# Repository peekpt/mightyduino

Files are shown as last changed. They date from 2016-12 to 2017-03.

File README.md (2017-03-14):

## Mightyduino
A DIY Arduino type hardware board based on ATmega644p Atmega1284p

This project is free and based on @MCUDude's [MightyCore](https://github.com/MCUdude/MightyCore) which has awesome well designed kits for serious development with AVR's.
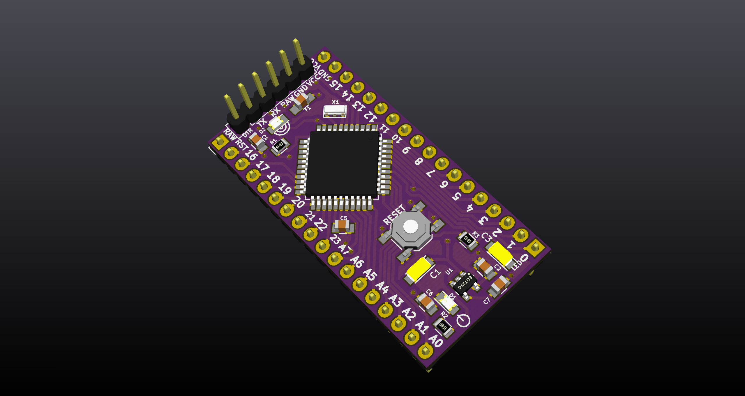
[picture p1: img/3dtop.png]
top


Mightyduino is an Arduino with more memory than an Arduino Pro mini. It can use 644p (64k) or 1284p (128k) chips. Its voltage can be configured by U1 and the frequecy can be configured by the Murata's ressonator (crystal).
It has a power led and another one connected to pin D0. The push button performs reset. DTR pin can be used to external reset. The RAW pin is the input voltage **<16v**. The VCC pin is the regulator output and IC voltage, it can be loaded up to peak of **500mA**.

To burn the **bootloader** (optiboot 6.0) you must first install the [MightyCore boards](https://github.com/MCUdude/MightyCore#how-to-install) on Arduino App  , connect the ICSP pins to your bootloader programming hardware (eg. USBASP), select one of MCUDude's board that meet the specs you use and burn bootloader.
Then you can access (ttl-serial dongle) like a normal arduino on the serial pins (like arduino pro mini). Mightyduino uses the 'standard' pin mapping.

###Version History
- v1.3 - Changed C1 C3 footprint, add reset pin for SPI programming.
- v1.2 - Switch U1 shutdown pin 3 voltage to RAW
- v1.1 - Switched Led from pin D13 to D0, cosmetic improvements
- v1.0 - Initial release

###Quick Links:

Order boards from [OSHPark]
(https://oshpark.com/shared_projects/zuZ4OIae)

Or download the [Gerber files](https://github.com/peekpt/mightyduino/raw/master/gerber/gerbers.zip) for other pcb maker

Download the schematic [PDF](https://github.com/peekpt/mightyduino/blob/master/schematic.pdf)

ATmega datasheet [644p](http://www.atmel.com/images/doc2593.pdf) [1284p](http://www.atmel.com/images/doc8059.pdf)

## Screenshots

###Components
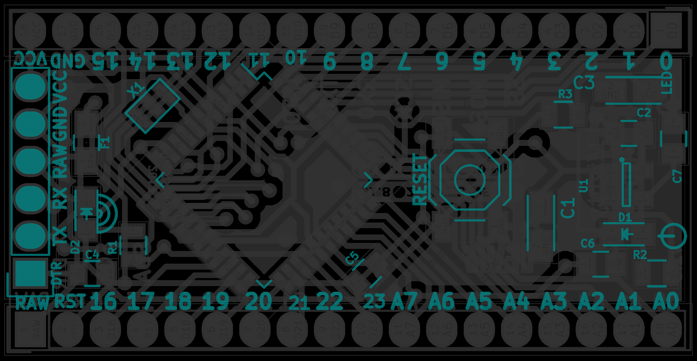
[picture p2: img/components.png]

### Top
top
### Bottom
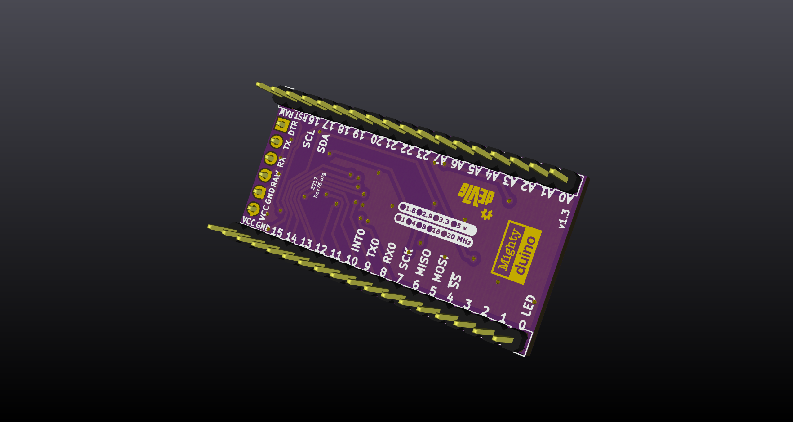
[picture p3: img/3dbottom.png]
bottom

###Pin Mapping
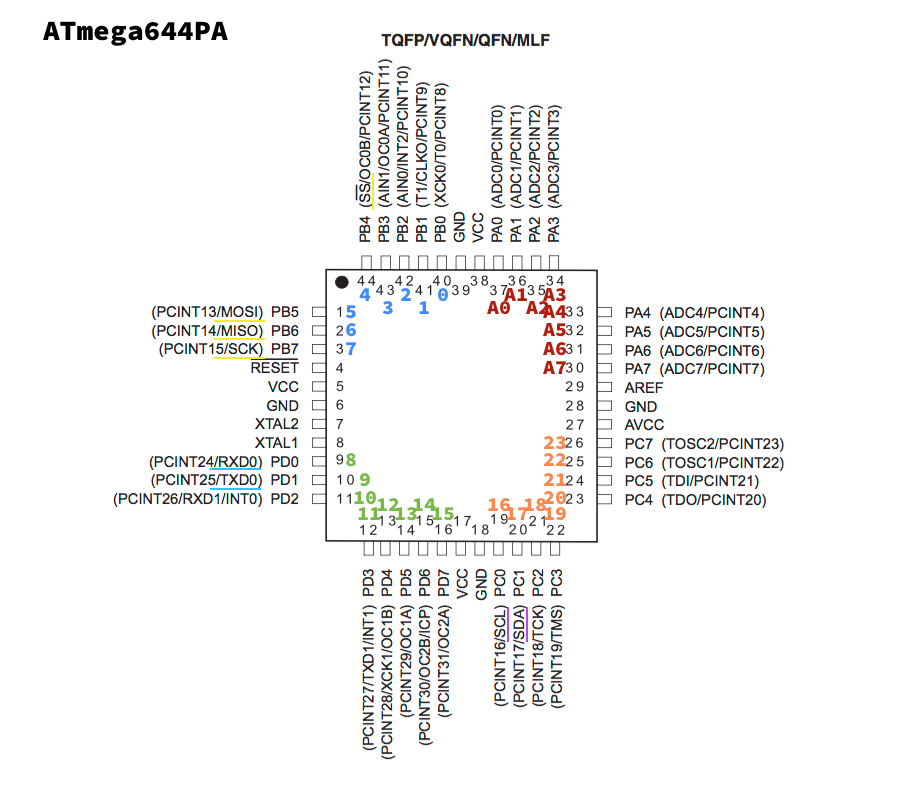
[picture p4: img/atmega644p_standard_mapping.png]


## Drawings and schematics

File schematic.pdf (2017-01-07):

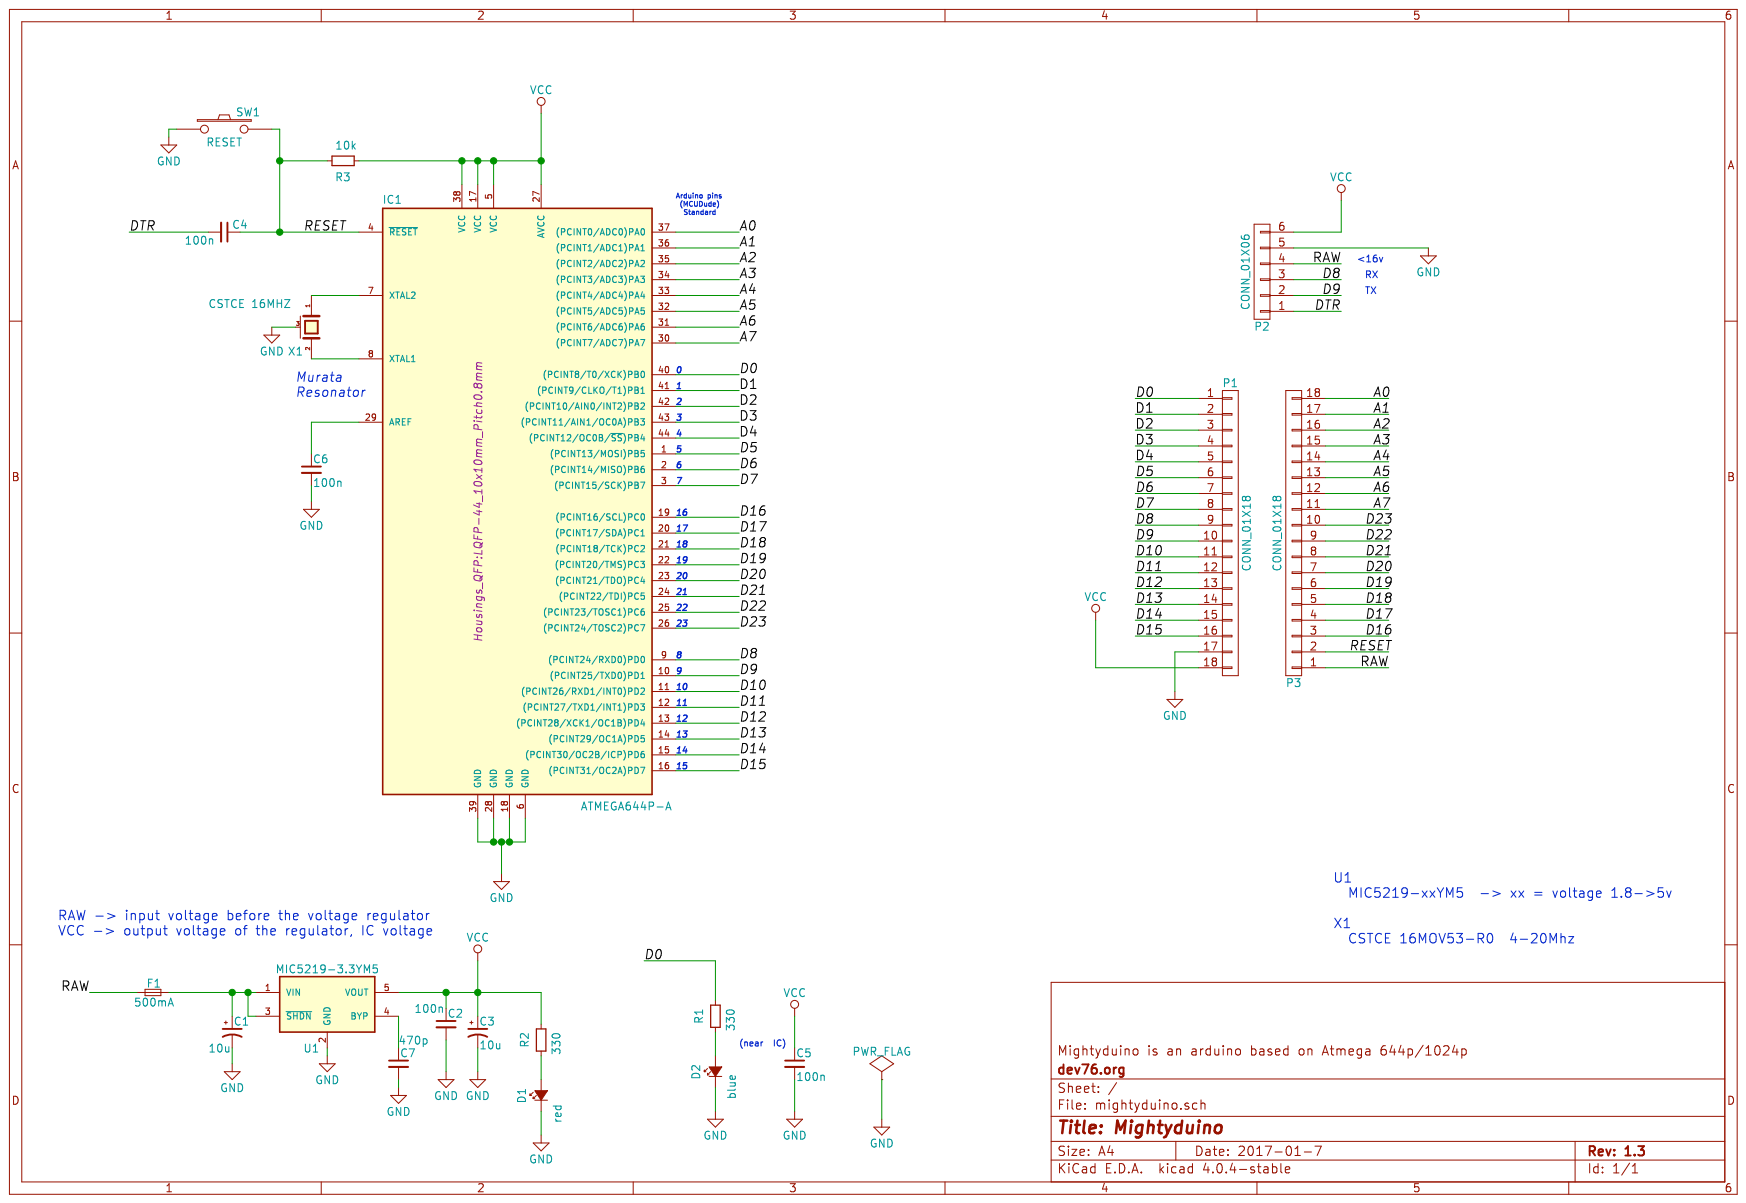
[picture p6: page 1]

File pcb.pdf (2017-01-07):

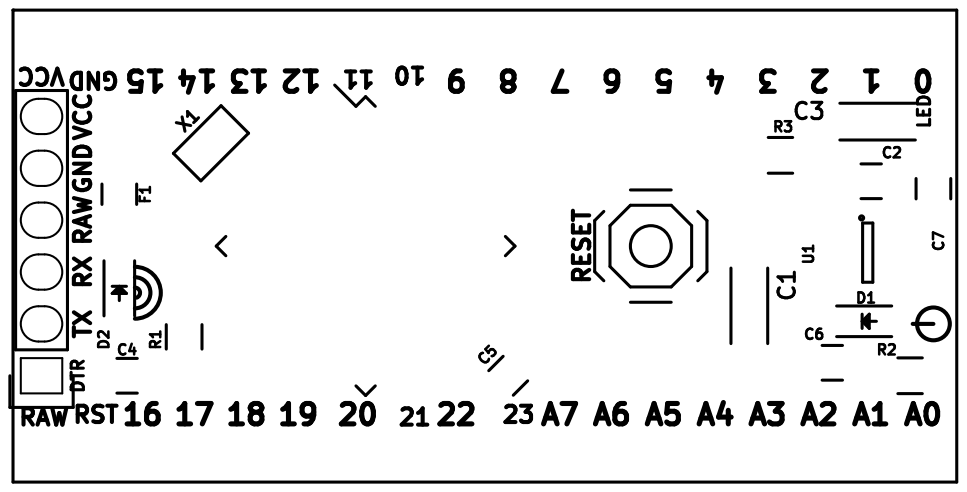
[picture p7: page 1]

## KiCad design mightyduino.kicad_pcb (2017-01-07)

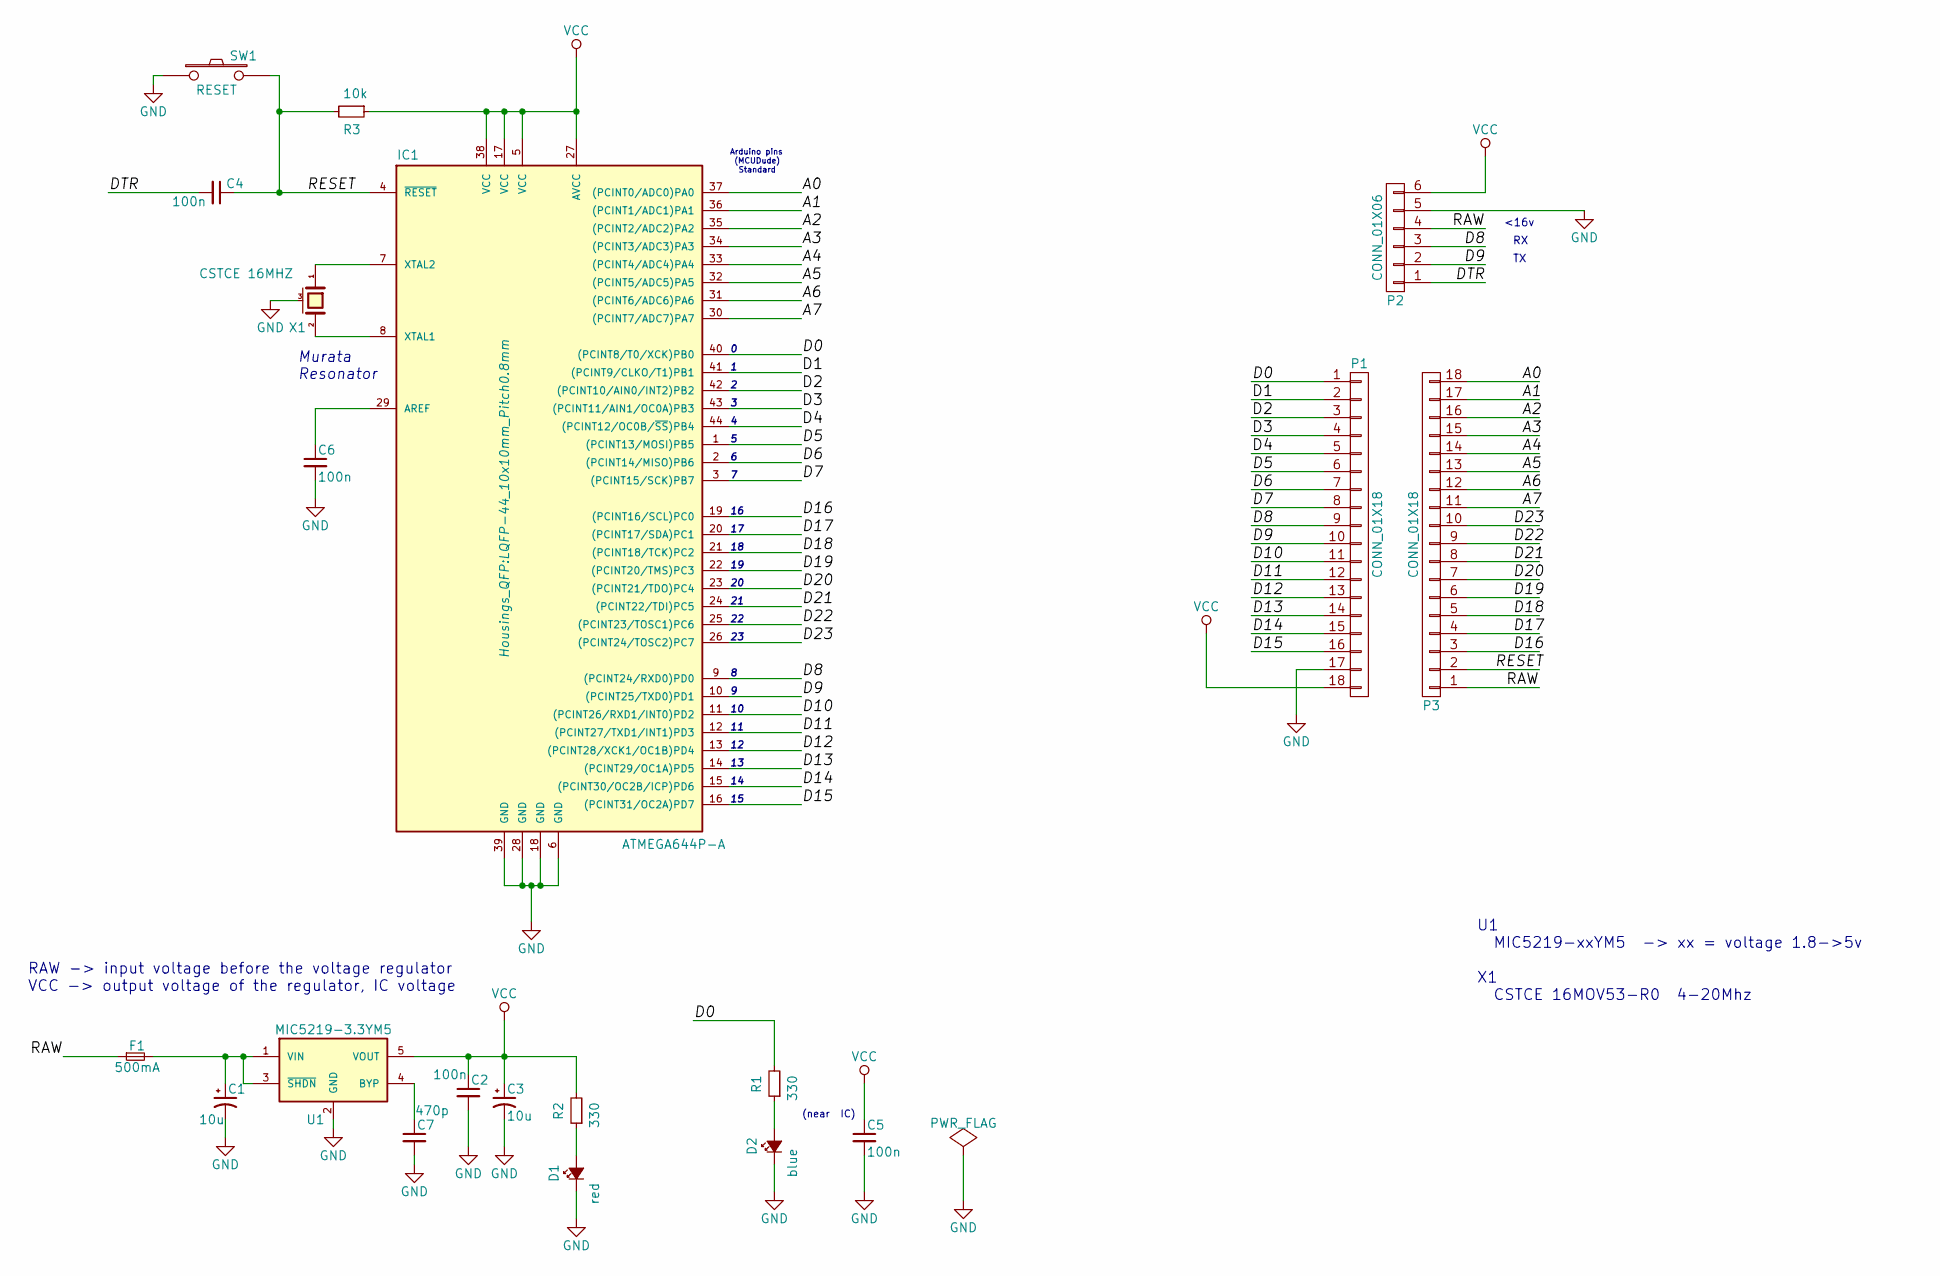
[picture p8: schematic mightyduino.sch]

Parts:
C1, C3: 10u; TantalC_SizeA_EIA-3216_Reflow
C2, C4, C5, C6: 100n; C_0805
C7: 470p; C_0805
D1: red; LED_0805
D2: blue; LED_0805
F1: 500mA; C_0805_HandSoldering
IC1: ATMEGA644P-A; LQFP-44_10x10mm_Pitch0.8mm
P1, P3: CONN_01X18; Pin_Header_Straight_1x18
P2: CONN_01X06; Pin_Header_Straight_1x06
R1, R2: 330; R_0805
R3: 10k; R_0805
SW1: RESET; SW_SPST_TL3342
U1: MIC5219-3.3YM5; SOT-23-5
X1: CSTCE 16MHZ; CSTCEv2

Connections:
/A0: IC1.37 ((PCINT0/ADC0)PA0), P3.18
/A1: IC1.36 ((PCINT1/ADC1)PA1), P3.17
/A2: IC1.35 ((PCINT2/ADC2)PA2), P3.16
/A3: IC1.34 ((PCINT3/ADC3)PA3), P3.15
/A4: IC1.33 ((PCINT4/ADC4)PA4), P3.14
/A5: IC1.32 ((PCINT5/ADC5)PA5), P3.13
/A6: IC1.31 ((PCINT6/ADC6)PA6), P3.12
/A7: IC1.30 ((PCINT7/ADC7)PA7), P3.11
/D0: IC1.40 ((PCINT8/T0/XCK)PB0), P1.1, R1.2
/D1: IC1.41 ((PCINT9/CLKO/T1)PB1), P1.2
/D2: IC1.42 ((PCINT10/AIN0/INT2)PB2), P1.3
/D3: IC1.43 ((PCINT11/AIN1/OC0A)PB3), P1.4
/D4: IC1.44 ((PCINT12/OC0B/~SS~)PB4), P1.5
/D5: IC1.1 ((PCINT13/MOSI)PB5), P1.6
/D6: IC1.2 ((PCINT14/MISO)PB6), P1.7
/D7: IC1.3 ((PCINT15/SCK)PB7), P1.8
/D8: IC1.9 ((PCINT24/RXD0)PD0), P1.9, P2.3
/D9: IC1.10 ((PCINT25/TXD0)PD1), P1.10, P2.2
/D10: IC1.11 ((PCINT26/RXD1/INT0)PD2), P1.11
/D11: IC1.12 ((PCINT27/TXD1/INT1)PD3), P1.12
/D12: IC1.13 ((PCINT28/XCK1/OC1B)PD4), P1.13
/D13: IC1.14 ((PCINT29/OC1A)PD5), P1.14
/D14: IC1.15 ((PCINT30/OC2B/ICP)PD6), P1.15
/D15: IC1.16 ((PCINT31/OC2A)PD7), P1.16
/D16: IC1.19 ((PCINT16/SCL)PC0), P3.3
/D17: IC1.20 ((PCINT17/SDA)PC1), P3.4
/D18: IC1.21 ((PCINT18/TCK)PC2), P3.5
/D19: IC1.22 ((PCINT20/TMS)PC3), P3.6
/D20: IC1.23 ((PCINT21/TDO)PC4), P3.7
/D21: IC1.24 ((PCINT22/TDI)PC5), P3.8
/D22: IC1.25 ((PCINT23/TOSC1)PC6), P3.9
/D23: IC1.26 ((PCINT24/TOSC2)PC7), P3.10
/DTR: C4.2, P2.1
/RAW: F1.1, P2.4, P3.1
/RESET: C4.1, IC1.4 (~RESET), P3.2, R3.2, SW1.2
GND: C1.2, C2.2, C3.2, C5.2, C6.2, C7.2, D1.1 (K), D2.1 (K), IC1.6 (GND), IC1.18 (GND), IC1.28 (GND), IC1.39 (GND), P1.17, P2.5, SW1.1, U1.2 (GND), X1.3 (case)
unnamed: C1.1, F1.2, U1.1 (VIN), U1.3 (~SHDN~)
unnamed: C6.1, IC1.29 (AREF)
unnamed: C7.1, U1.4 (BYP)
unnamed: D1.2 (A), R2.1
unnamed: D2.2 (A), R1.1
unnamed: IC1.7 (XTAL2), X1.1
unnamed: IC1.8 (XTAL1), X1.2
VCC: C2.1, C3.1, C5.1, IC1.5 (VCC), IC1.17 (VCC), IC1.27 (AVCC), IC1.38 (VCC), P1.18, P2.6, R2.2, R3.1, U1.5 (VOUT)

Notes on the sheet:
Murata Resonator
Arduino pins (MCUDude) Standard
(near IC)
<16v
U1 MIC5219-xxYM5 -> xx = voltage 1.8->5v X1 CSTCE 16MOV53-R0 4-20Mhz
RAW -> input voltage before the voltage regulator VCC -> output voltage of the regulator, IC voltage

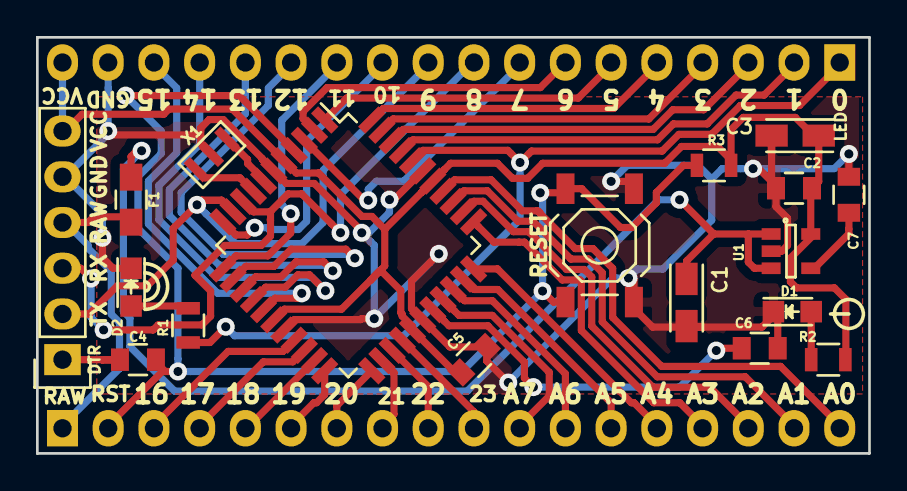
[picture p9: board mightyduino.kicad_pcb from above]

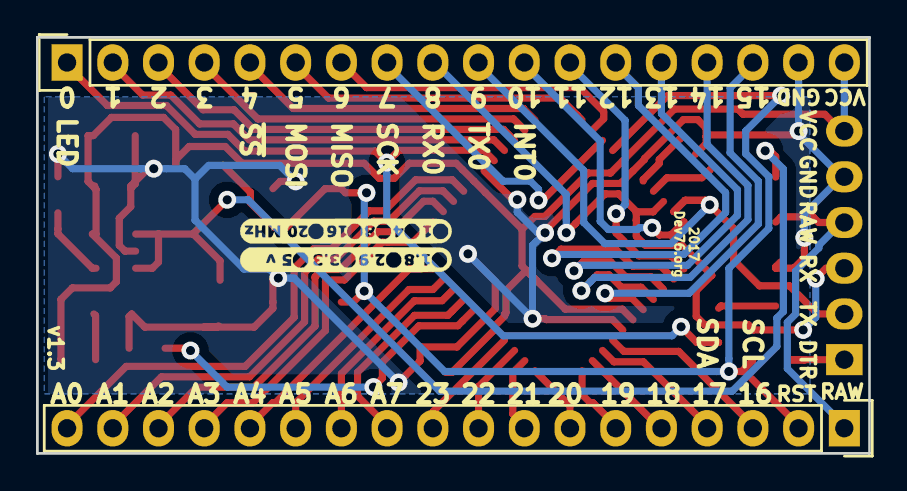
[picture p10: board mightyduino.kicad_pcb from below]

Board: 2 copper layers, 46.2 x 23.1 mm, 20 parts (2 on the bottom side), 44 nets.

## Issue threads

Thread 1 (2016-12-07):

Led on D13

peekpt, 2016-12-07:
Need to change led to D0 to meet the boot loader blink notification on reset.

peekpt, 2016-12-07:
done in v1.1

Closed 2016-12-07.

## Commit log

2016-12-05 Public release 1.0
    [mightyduino-B.Cu.gbl, mightyduino-B.Mask.gbs, mightyduino-B.Paste.gbp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]
2016-12-07 switched led from d13 to d0, cosmetic improvments
    [mightyduino-B.Cu.gbl, mightyduino-B.Mask.gbs, mightyduino-B.Paste.gbp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]
2016-12-09 fix U1 pin 3 enable voltage
2016-12-11 updated ressonator 3d design
    [mightyduino-B.Cu.gbl, mightyduino-B.Mask.gbs, mightyduino-B.Paste.gbp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]
2017-01-04 Removed front Silk logo (too small for printing)
2017-01-07 C1,C3 better footprint, added RESET PIN
    [mightyduino-B.Cu.gbl, mightyduino-B.Mask.gbs, mightyduino-B.Paste.gbp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]
2017-01-18 Added project footprintslibrary
